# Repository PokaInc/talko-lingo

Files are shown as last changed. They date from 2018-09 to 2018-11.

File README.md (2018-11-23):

# Talko-Lingo
A demonstration project for the re:Invent Builder's Fair 2018

## Abstract

### Talko-Lingo: The multilingual Walkie Talkie

Talko-Lingo enables near real-time communication between two people of the same
or different languages. Users interface with a Walkie Talkie consisting of a
Raspberry Pi embedded into a 3D printed device. After selecting their language,
each user can seamlessly communicate with the recipient, who may be speaking a
different language. The project leverages AWS cloud technologies to encode each
user's voice, transcribe it, translate it to the target language and then
finally convert the translated text to speech. Built-in display mechanisms
provide visual feedback of the translation process.

### Project setup

#### A note for Windows users

The project has been built using Unix-like systems (OSX and Linux), and
therefore our instructions are Unix-oriented. We think that the easiest way to
deploy Talko-Lingo on Windows would be to spin-up a small `Docker` linux
container and follow our instructions, but there is no reason why you couldn't
setup the project on a Windows system using something like `MinGW`. Also, note
that the core of our code is python-based, which is cross-platform so the only
thing an experienced user would have to adapt would be our `bash` and `make`
deploying scripts, which you can work-around with native utilities.

#### Prerequisites: Shared resources

In order to deploy the Cloud resources required by the Talko-Lingo project, we
have prepared some CloudFormation templates for you.

It provisions the following resources:
- An audio bucket that will be used as temporary storage for the audio
processing
- The Tx and Rx lambdas, respectively used for transmitting messages to the
other party and receiving the responses.
- The IoT resources used to publish and subscribe to MQTT topics
- A Web UI to follow the progress of messages through the pipeline

In order to get started, open your AWS console in your browser. On the
command-line you should be able to simply execute the following command to get
things deploying:

```
make deploy-talko-lingo
```

After a couple of minutes, you should start to see resources being created in
your environment:
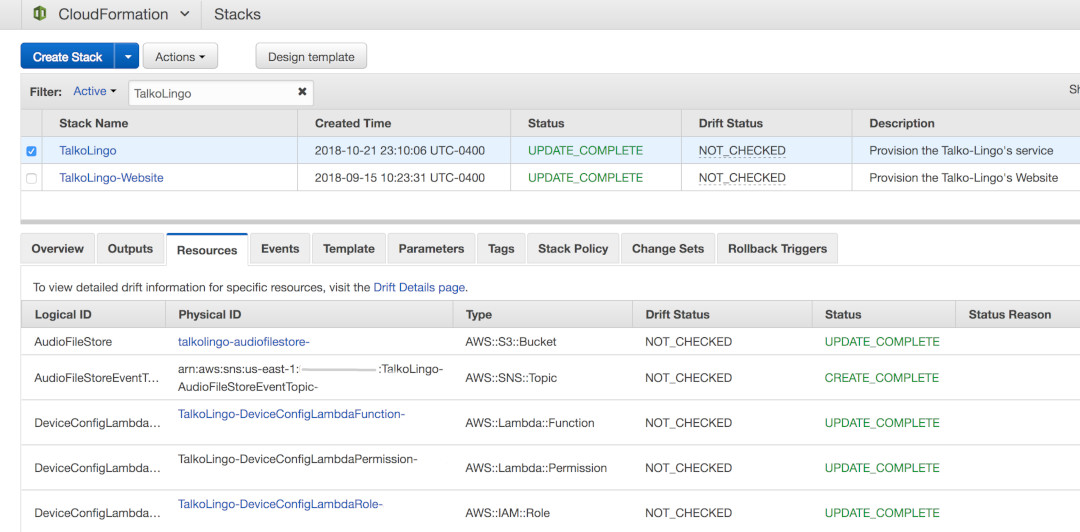
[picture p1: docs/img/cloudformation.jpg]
CloudFormation Cloudformation reosurces


#### Project Setup

In order to complete your own Talko-Lingo pair of Walkie-Talkies, we did put
together a step-by-step tutorial to get you going. Note that these are only
suggestions and we encourage you to make you own version of these if your setup
differs from ours: There are many ways to adapt this project to other types of
hardwares.

2. [Raspberry Pi Software Setup](docs/README_RASPBERRY_PI.md)
3. [Raspberry Pi Hardware Setup](docs/README_HARDWARE.md)
4. [Case 3D Printing](docs/README_3D_PRINTING.md)

If all is went well, you should have a fully-functional Walkie-Talkie setup!
As a bonus, you can tweak it to work over WiFi and communicate over hundreds of
kilometers :-)

And if you want to contribute, of course we accept PRs :-)

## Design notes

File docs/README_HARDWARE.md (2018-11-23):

## Required hardware

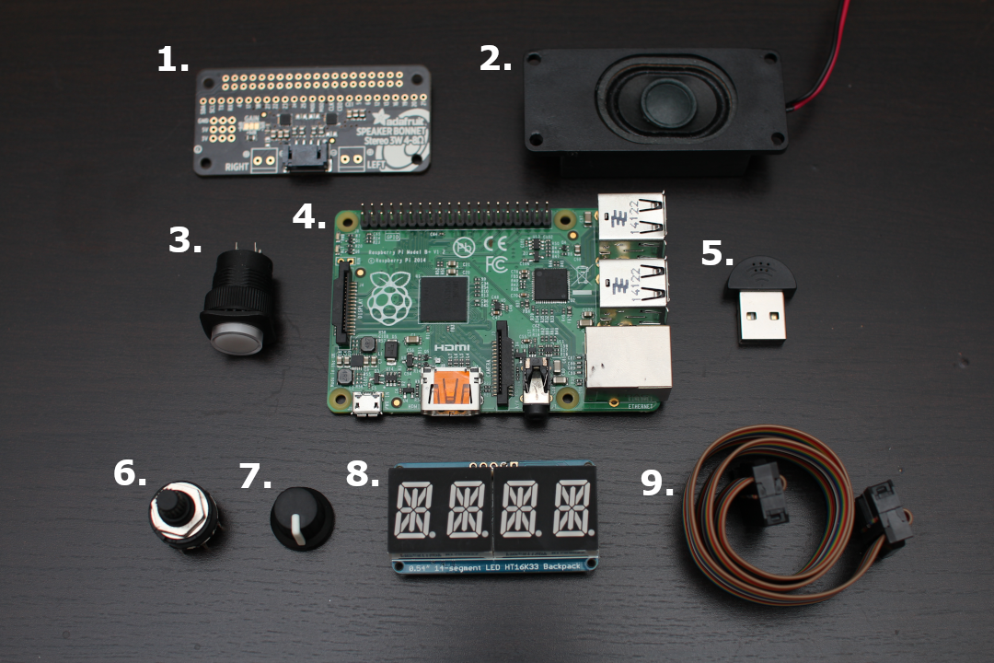
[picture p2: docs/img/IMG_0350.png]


In order to complete this project, you will need two copies of each of those things:

1. **Adafruit's Speaker Bonnet**: An I2S stereo amplifier for the Raspberry Pi. It connects directly to the GPIO and exposes most useful pins. *Warning*: It makes use of pins **19** and **21** even if they are re-exposed. Do not use them if you intend to play sound at the same time. [Available here](https://www.adafruit.com/product/3346)
2. **Adafruit's 3W 4Ohm Speakers**: The speakers normally coming with the bonnet aforementioned. [Available here](https://www.adafruit.com/product/3351)
3. **Adafruit's 16mm Illuminated Pushbutton**: A simple push button equipped with a 3V LED light. [Available here](https://www.adafruit.com/product/1479)
4. **A Raspberry Pi 3**: We made our tests using a Raspberry Pi model B, but a model A, B+ or A+ should work just as well... [Available here](https://www.buyapi.ca/product/raspberry-pi-3-model-b-plus/)
5. **Adafruit's Mini USB Microphone**: A very simple microphone. Be careful, from what we have tested, the quality can be inconsistent... [Available here](https://www.adafruit.com/product/3367)
6. **Adafruit's Mini 8-Way Rotary Selector Switch**: We chose an 8-position rotary switch, but a rotary encoder could be a superior choice. [Available here](https://www.adafruit.com/product/2925)
7. **Adafruit's Potentiometer Knob**: Just to put on the previously mentioned Rotary Selector so that it looks *sexier*. [Available here](https://www.adafruit.com/product/2047)
8. **Adafruit's Alphanumeric Display with its I2C Backpack**: Adafruit has a really easy-to-use LED alphanumeric display, including very well detailed tutorial for Raspberry Pi.. [Available here](https://www.adafruit.com/product/1911)
9. **A flat ribbon cable**: We chose to use a rainbow-colored flat ribbon for ease of use, but really anything you have on-hand will do the job ;-)

## Other required tools

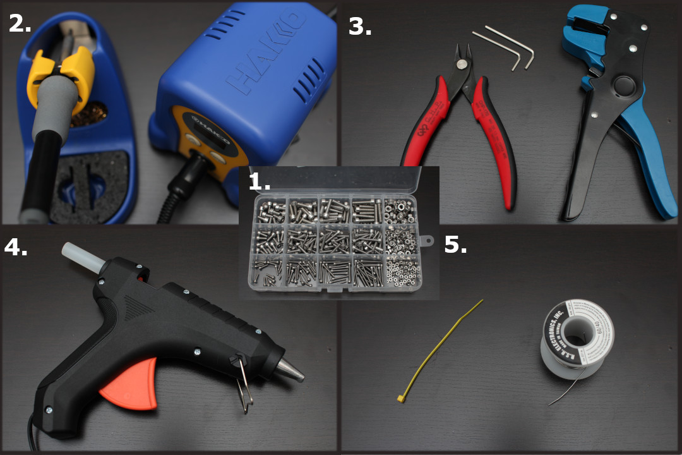
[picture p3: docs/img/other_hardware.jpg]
Required hardware


1. **A set of electronic-sized screws**: Our [3D model]() *--Include Fusion3D gallery link--* includes placeholders for 2mm x 22mm screws. If you don't have the exact screw model we used, you can always modify the model's [parameters](https://www.youtube.com/watch?v=apkUQKNwHIo) to fit your needs.

2. **A soldering iron**: This project requires quite a bit of soldering, so you will have to find a soldering iron. There are a lot of different qualities, but in our case we used the [Hakko FX888D]( https://www.hakko.com/english/products/hakko_fx888d.html) model.

3. **Wire-cutting instruments**: Again, a nice-to-have but those will just make your life easier.

4. **A glue gun with sticks**: This one might not be absolutely necessary, but we found that it helps protecting and solidifying the whole setup against short-circuits and accidental impacts.

5. **Soldering lead**: Of course you will need some lead to do soldering. We used [RSR Electronic's](https://www.elexp.com/ProductDetails.aspx?item_no=060701&CatId=c98e6dbc-415b-4cfe-8661-15f3ec0b88ec) Resin-cored spool. It is much easier to work with for newbies like us, but do not abuse it because it contains toxic chemicals.

## Assembly

### The wires

First, you will need to prepare some cables to connect the components to the speaker bonnet. In our setup, we used these cable lengths:

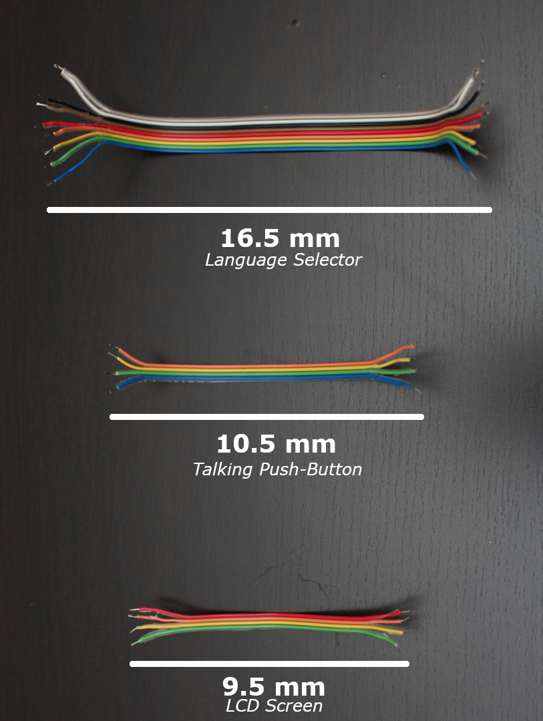
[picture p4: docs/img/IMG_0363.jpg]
Cable lengths


Next, you should begin by soldering the individual components to the aforementioned wires. By convention, we tried to keep red/orange wires for positive DC current and black/blue wires for the ground, but we couldn't follow those standards all the way.

In our case, the result looks like this:

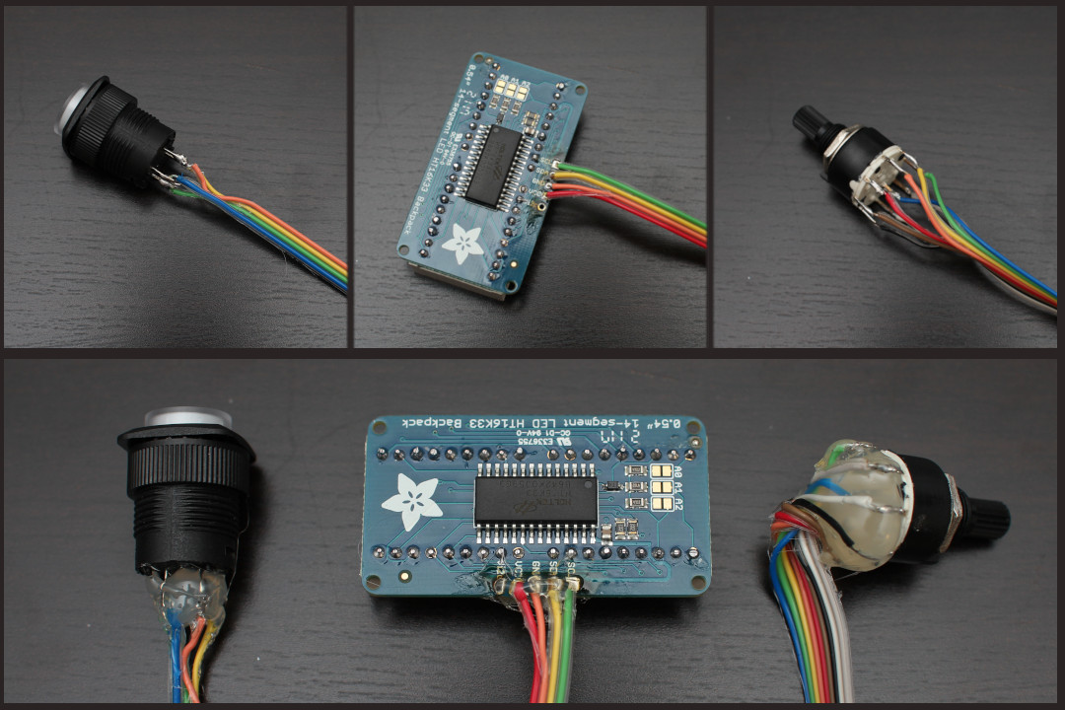
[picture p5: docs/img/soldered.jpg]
Soldered Soldered elements


Notice that as previously said, we used hot glue in order to isolate and harden the fragile wires to our components. There is probably a more professional way, but this one works well for our use-case and is cheap and easy to use.

### The speaking push-button

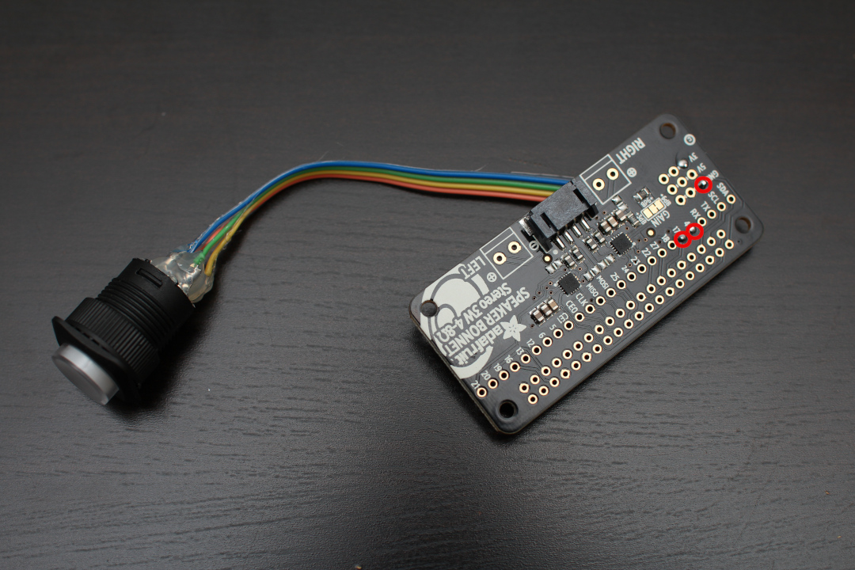
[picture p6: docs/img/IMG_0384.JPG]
PushButton LED Push Button


Once the components are soldered to their wires, you can go-on and begin hooking-them up to the speaker bonnet. We suggest starting with the push-button with the following pin associations:

- The negative (-) pin of the push-button and one of the data pins together in one of the ground pins of the speaker bonnet, since all the ground wires of the circuit are considered the same, and we will need all of them.

- The positive (+) pin of the push-button hooked to the GPIO pin #4 of the speaker bonnet. In theory, we would also need a small resistance (220Ω to 1000Ω) just to be sure, but our tests seem to be conclusives without one...

- The last data pin of the push button to the GPIO pin #17. This will be used to trigger when the user has something to say.

### The LED display

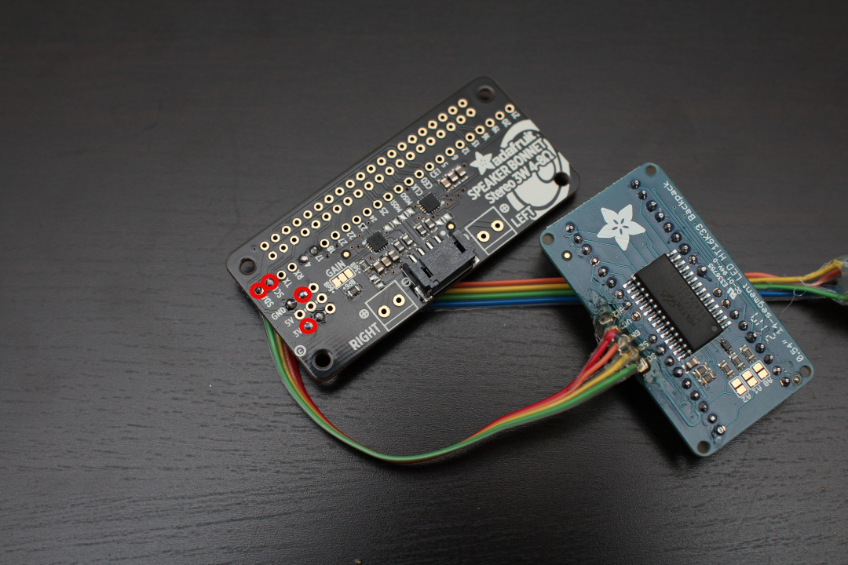
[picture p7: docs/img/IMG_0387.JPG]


This component is pretty straight-forward, you only have 4 wires to solder (plus the LED displays to their backpack, of course...):

- The VCC (+) and GND (-) are soldered to a 3.3V and a ground pin from the speaker bonnet respectively. Note that we do not use the Vi2c pin, so make sure you have the good one.

- SDA and SCL are soldered to their respective pins on the speaker bonnet. **Note that the pins are inverted on the LED backpack compared to the bonnet.** Make sure you don't invert them or it will not work.

### The rotary selector switch

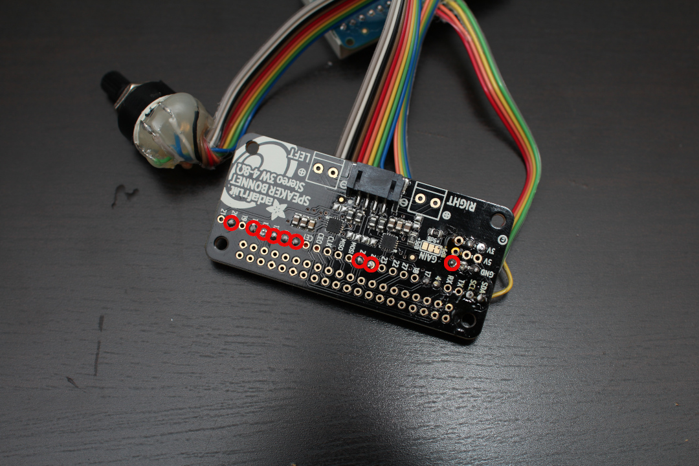
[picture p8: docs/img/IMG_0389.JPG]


This last component needs a little more attention, as there are 9 pins to solder:

- There is a "centered" pin which we will use to connect the ground.

- The other pins will be soldered to GPIO pins #20, 16, 13, 12, 6, 5, 25 and 24.

Note that the choice of pin is arbitraty, but you **cannot choose the pins 19 or 21**, as they are reserved by the speaker bonnet.

### Final result

The final result should look like something similar to this:

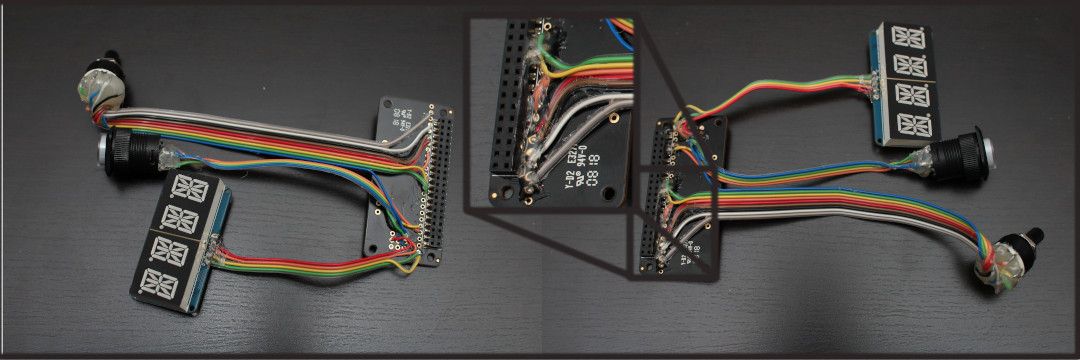
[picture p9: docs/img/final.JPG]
Final result


On the left part, you have the resulting piece of hardware that has just been soldered. But in order to protect our newly soldered wiring, the right side of the picture shows how we used hot glue to isolate and harden a bit our setup.

Proceed to the [next step](README_3D_PRINTING.md) to handle the 3D-printing part of the Talko-Lingo project.

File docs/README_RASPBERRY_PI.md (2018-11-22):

# Raspberry Pi Setup

### Overview
We'll start by configuring the Pi and installing the required softwares. We'll
then clone the project add the appropriate environment variables. Once we get
the code running and we're satisfied wit the setup, we'll duplicate the Micro SD
card so we can get the second Raspberry Pi working without manual interactions.

## Configuring the Pi

### Installing the OS
First you need to get [Raspbian Stretch Lite](https://www.raspberrypi.org/downloads/raspbian/) installed on a Micro SD
Card. I won't go into too much details as there is already great
[documentation](https://www.raspberrypi.org/documentation/installation/installing-images/README.md) that can be found
on the official Raspberry Pi website.

### Getting access to the terminal

There's a few ways to get access to your Raspberry Pi's terminal, but one of the simplest one is just to plug a keyboard
 and a monitor. You'll then need to login, by default the username is `pi` and the password is `raspberry`.

### Basic configuration
In the terminal run the Raspberry Pi configurator:
```
sudo raspi-config
```

#### Change the default password
Considering your Pi will have to be connected to the internet, start by changing the default password to something
else.

#### Network configuration
Open the `Network Options` menu. Change the hostname to something like `talko-a`. Unless you planned to use an ethernet
cable to connect to the internet you'll have to setup the `Wi-fi`. Start by setting the name of your Wi-fi (SSID) and
then input the password. A good way to make sure the Wi-fi was properly configured is to run the `Update` command from
`raspi-config`.

#### Interfacing configuration
Still in `raspi-config`, now navigate to `Interfacing Options`. If you're planning to connect to your Raspberry Pi's
terminal with your computer instead of relying on the keyboard and monitor combo, enable SSH. Then enable I2C as it is
required for the LED display and possibly the speaker bonnet.

### Software installation

In the terminal run the following commands:
```
sudo apt-get update
sudo apt-get install -y build-essential python-dev python-pip python-smbus python-imaging git libportaudio2 portaudio19-dev libsndfile1 libffi-dev mpg321
```

There is a special dependency that needs to be installed for the LED
alphanumerical display to work.
```
git clone https://github.com/adafruit/Adafruit_Python_LED_Backpack.git
cd Adafruit_Python_LED_Backpack
sudo python setup.py install
```

Finally, install [Adafruit's Speaker Bonnet](). You can find the detailed instructions on their [website tutorial](https://learn.adafruit.com/adafruit-speaker-bonnet-for-raspberry-pi/raspberry-pi-usage), but in our case, here is the simplest method what worked for us:

```
curl -sS https://raw.githubusercontent.com/adafruit/Raspberry-Pi-Installer-Scripts/master/i2samp.sh | bash
```

It will ask you to confirm install-steps two times by pressing `y`, then you
will have to reboot the Pi for the changes to take effect.

#### Optional peaker bonnet tweaks

Then, for a clearer sound and to enable volume control, you should follow [these Adafruit instructions](https://learn.adafruit.com/adafruit-speaker-bonnet-for-raspberry-pi/i2s-tweaks) on the Pi:

First, add `dtoverlay=i2s-mmap` to the file `/boot/config.txt`:
```
...
# Enable audio (loads snd_bcm2835)
#dtparam=audio=on
dtoverlay=hifiberry-dac
dtoverlay=i2s-mmap
```

Then modify `/etc/asound.conf` so that it looks like this:

```
pcm.speakerbonnet {
   type hw card 0
}

pcm.!default {
   type plug
   slave.pcm "dmixer"
}

pcm.dmixer {
   type dmix
   ipc_key 1024
   ipc_perm 0666
   slave {
     pcm "speakerbonnet"
     period_time 0
     period_size 1024
     buffer_size 8192
     rate 44100
     channels 2
   }
}

ctl.dmixer {
  type hw card 0
}
```

Which creates a PCM sound device with good default parameters.

Finally, create a new file `/home/pi/.asoundrc`
```
pcm.speakerbonnet {
   type hw card 0
}

pcm.dmixer {
   type dmix
   ipc_key 1024
   ipc_perm 0666
   slave {
     pcm "speakerbonnet"
     period_time 0
     period_size 1024
     buffer_size 8192
     rate 44100
     channels 2
   }
}

ctl.dmixer {
    type hw card 0
}

pcm.softvol {
    type softvol
    slave.pcm "dmixer"
    control.name "PCM"
    control.card 0
}

ctl.softvol {
    type hw card 0
}

pcm.!default {
    type             plug
    slave.pcm       "softvol"
}
```
Reboot in order for your changes to apply. Then, you have to play some sound
using `alsa`:
```
speaker-test -c2 --test=wav -w /usr/share/sounds/alsa/Front_Center.wav
```
And then **reboot again**. Also copy this file to `/root/.asoundrc`:
`sudo cp /home/pi/.asoundrc /root/.asoundrc` and of course **reboot again**.

Then, choose the sound level that you find appropriate for your device using
`sudo alsamixer`. Our testings suggest that 80% is a good level.

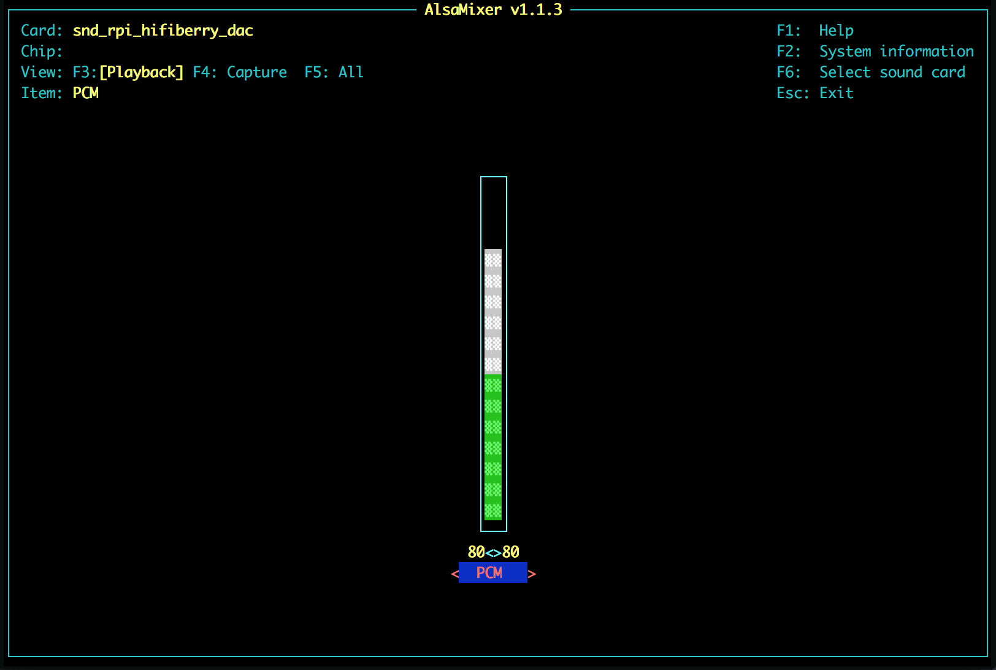
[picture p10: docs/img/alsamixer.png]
Alsa Mixer


*Note*: Never underestimate the power of rebooting when playing with sound on
the Raspberry Pi (and I would say on Linux in general). In our case, it solved
weird problems a couple of times when we were not quite sure what was going on.

### Device-specific AWS resources

For each device of the Talko-Lingo system (typically two), you have to deploy
specific Cloud resources, consisting mostly of what is needed for your device to
authenticate with AWS's `IoT-Data` topics. It will generate certificates which
you can copy to you Raspberry Pi and enable the TalkoLingo service.

To deploy `IoT-Data` credentials to your Raspberry Pi, you can just `make` them:

```
make raspberry-pi-credentials

...make normal outputs...

--------------------------------------------------------
Execute the following on device A terminal:
wget "https://<credentials_bucket>.s3.amazonaws.com/config.zip? \
      AWSAccessKeyId=<ACCESS_KEY_ID>& \
      Signature=<SIGNATURE>& \
      Expires=<TIMESTAMP>" \
      -O config.zip && \
      unzip config.zip -d /home/pi/talko-lingo/.config && \
      rm config.zip
-----------(Link will expire in 15 minutes)-------------
Press enter to continue
```

You can copy-paste this output to your Raspberry Pi; What is happening here is
that when generating the AWS `IoT-Data` credentials, the `make` script uploads
the credentials (certificates) to an S3 bucket and generates a signed link that
only lasts for 15 minutes for security measures. Then, it unzips the files to
the correct configuration directory to be able to publish to the good `IoT-Data`
topic.

### Talko-Lingo installation
In the pi's home directory (`/home/pi`) clone the project:
```
git clone https://github.com/PokaInc/talko-lingo.git
```
cd in the project folder for the next part:
```
cd talko-lingo
```

Install python requirements (be patient it takes a few minutes):
```
cd talko-lingo
pip install -r local_requirements.txt
```

Finally install the `systemd` service on the Raspberry Pi:
```
make install-raspberry-pi-service
```

Which install the `systemd` service associated with the Talko-Lingo software (`rx` and `tx`, which respectively receive and send the audio to the backend).

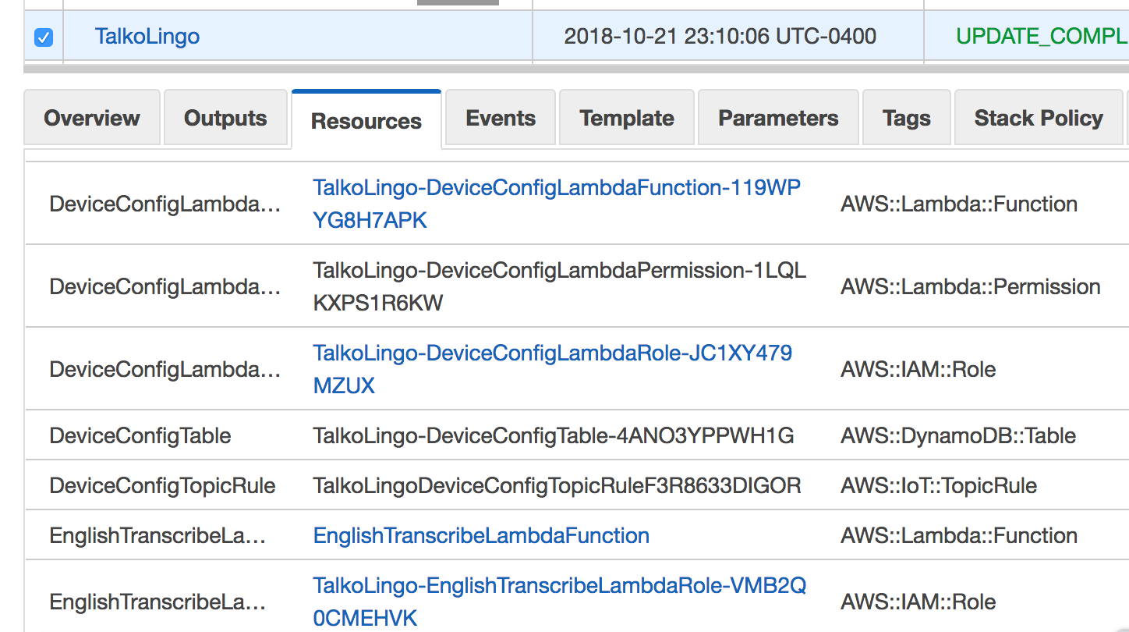
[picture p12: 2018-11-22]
docs/img/cloudformation.png

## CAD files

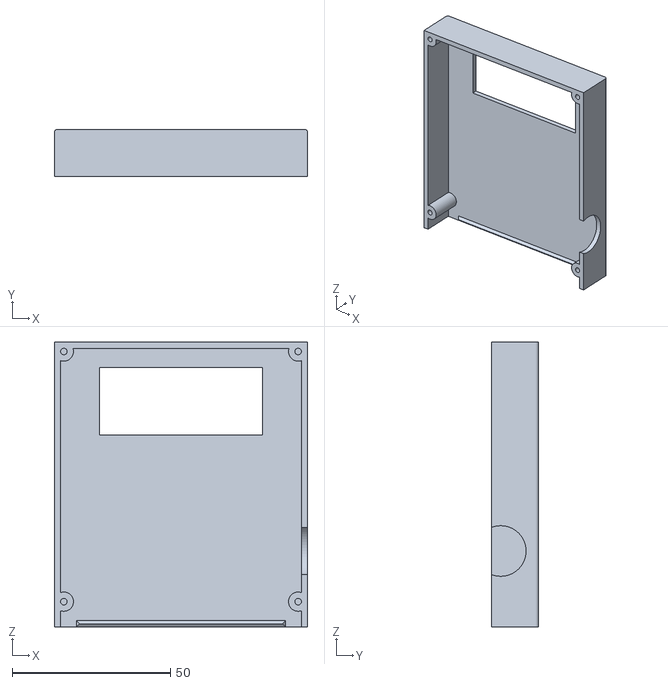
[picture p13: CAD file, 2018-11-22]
3d-printing/top_shell.stl
80.0 x 15.0 x 90.0

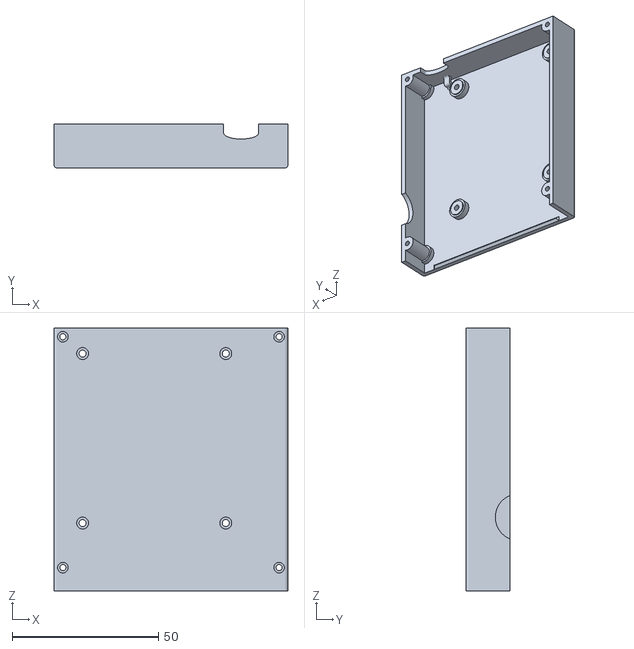
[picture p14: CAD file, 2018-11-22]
3d-printing/bottom_shell.stl
80.0 x 15.0 x 90.0

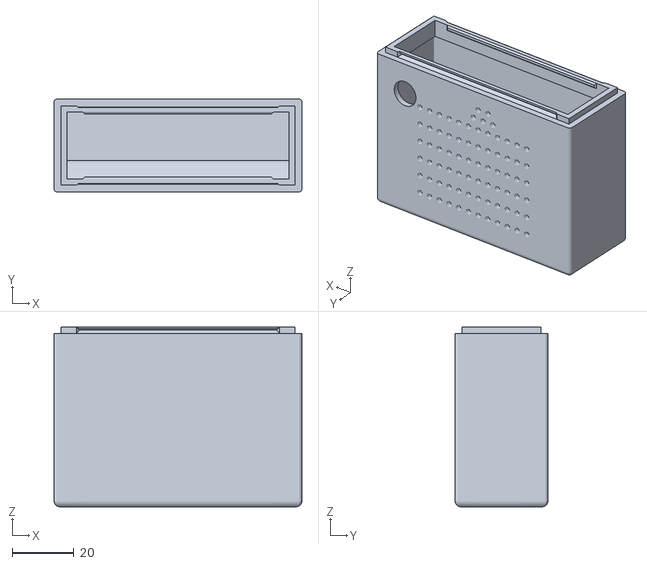
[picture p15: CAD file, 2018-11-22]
3d-printing/speaker_shell.stl
80.0 x 30.0 x 58.0

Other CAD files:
3d-printing/Talko-Lingo.f3d

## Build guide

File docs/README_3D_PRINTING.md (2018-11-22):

## 3D printing & Assembly

### Fusion 360

We designed our case using the [Fusion360](https://www.autodesk.com/products/fusion-360/overview) software. Although it is a commercial product, it is free for hobbyists, you just need to activate your license after installing the free trial.

You will find in the `3d-printing` folder of the present project everything you need to print the plastic-case yourself: the file `Talko-Lingo.f3d` can be imported directly to the Fusion 360 if you wish to make adjustments to the the model (adjusting screw sizes, for example).

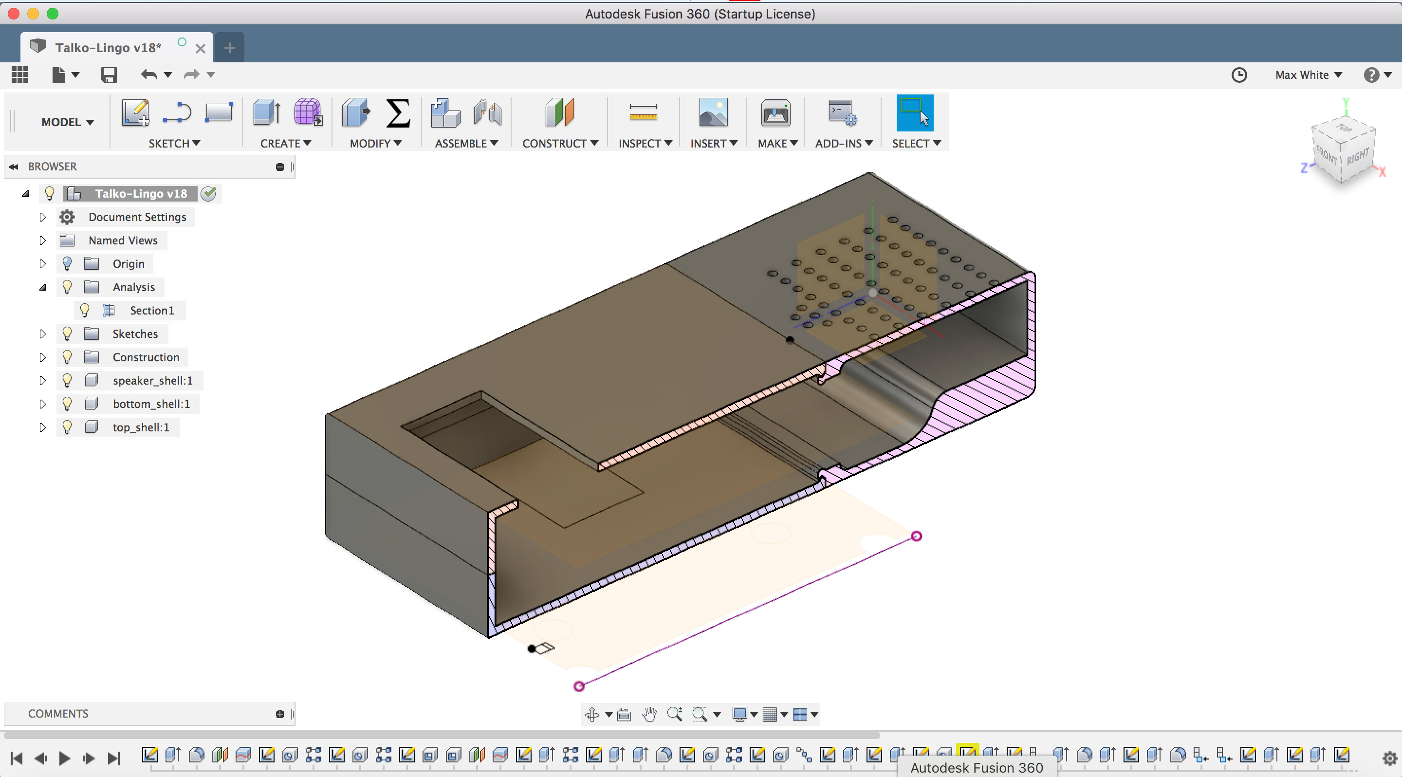
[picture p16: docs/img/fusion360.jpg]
Fusion 360


### Cura

The model is composed of three components: The bottom shell where the Raspberry Pi sits, the top shell where the screen is place and the speaker shell where the speaker, rotary switch and microphone are incorporated. You will find in the `3d-printing` folder of this repository the `STL` file of each of those components which you can send directly to a _slicer_ software like [Cura](https://ultimaker.com/en/products/ultimaker-cura-software).

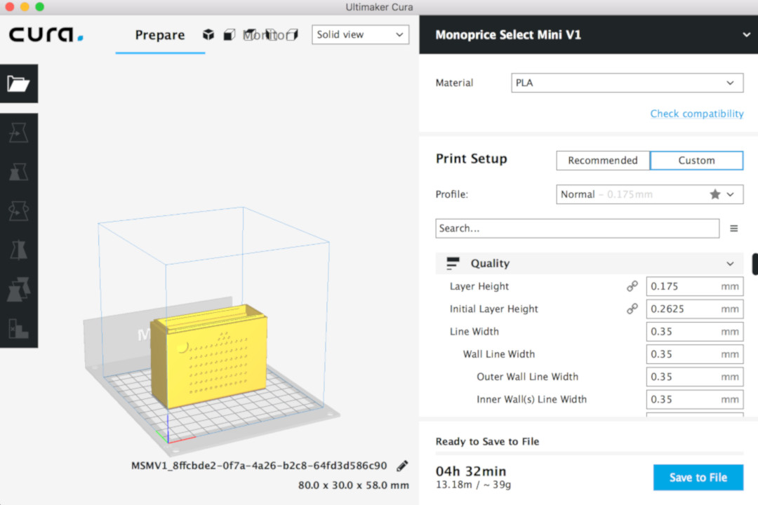
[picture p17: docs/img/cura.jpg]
Cura


It will take care of generating the `gcode` file that most printers will support. There is a pretty large amount of parameters, but Cura has a preset for most popular 3D printers on the market. In our case, we used a [Monoprice MP Select Mini V1](https://www.monoprice.com/product?c_id=107&cp_id=10724&cs_id=1072403&p_id=31429&seq=1&format=2) printer with default settings except for one thing: the `Start G-Code` and `End G-Code`, which we took from [their website](https://mpselectmini.com/starting_ending_g-code_scripts) and gives better overall performance. Our model does not need any "support", we suggest disabling them or you might have a hard time cleaning-up your print afterwards.

#### Starting G-code
 ```
G90 ; set to absolute positioning - this line was added in case Cura doesn't include it by default
M82 ; set extruder to absolute mode - this line was added in case Cura doesn't include it by default (may not be needed)
G28 ; home all axes
; The lines below are to prep the nozzle before a print begins
G1 Z0.2 F1200 ; raise nozzle 0.2mm
G92 E0 ; reset extrusion distance
G1 Y10 ; move Y-Axis (bed) 10mm to prep for purge
G1 X100 E12 F600 ; move X-carriage 100mm while purging 12mm of filament
G92 E0 ; reset extrusion distance
 ```
#### Ending G-code

```
M104 S0 ; turn off hotend/extruder heater
M140 S0 ; turn off bed heater
G91 ; set to relative positioning
G1 E-2 F300 ; retract the filament a bit before lifting the nozzle to release some of the pressure
G1 Z1 ; raise Z 1mm from current position
G1 E-2 F300 ; retract filament even more
G90 ; set to absolute positioning
G1 X20 ; move X axis close to tower but hopefully far enough to keep the fan from rattling
G1 Y120 ; move bed forward for easier part removal
M84 ; disable motors
G4 S360 ; keep fan running for 360 seconds to cool hotend and allow the fan to be turned off - adjust to your needs
M107 ; turn off fan. Don't use M106 S1. Some say M107 doesn't work for them but if the hotend is below 70 degrees it should work
```

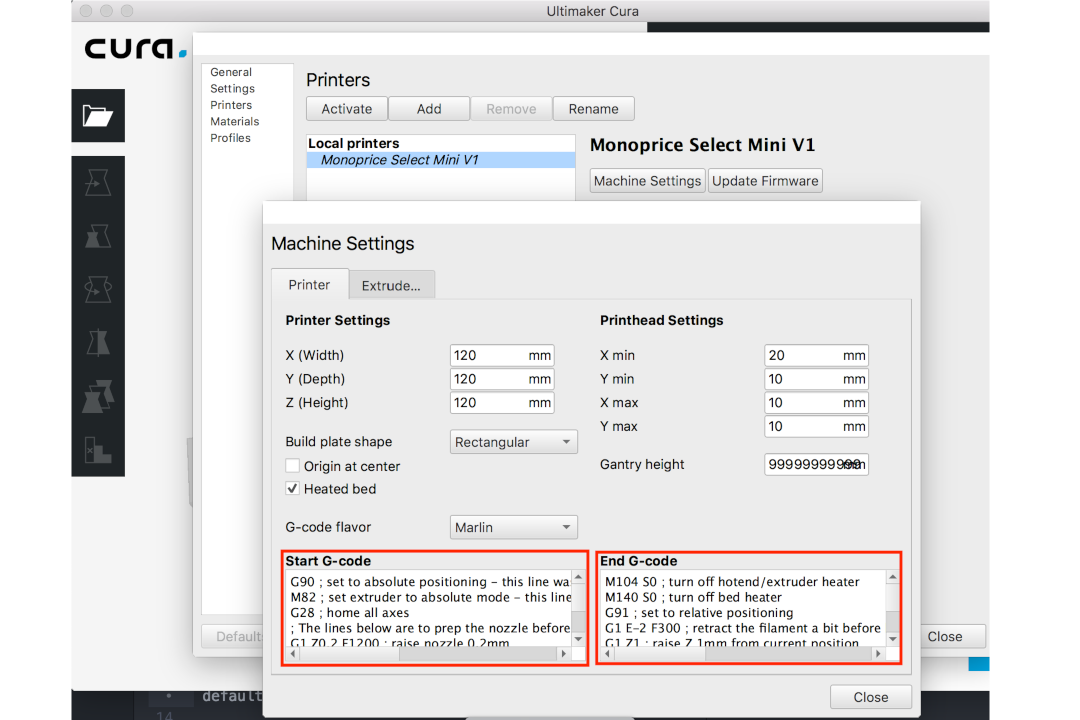
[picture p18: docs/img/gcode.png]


### OctoPrint

Finally, when the model has been sliced and we are satisfied with the preview it gives, the last stage before the actual printer was to upload it to OctoPi, a RaspberryPi equipped with the [OctoPrint](https://octoprint.org) software.

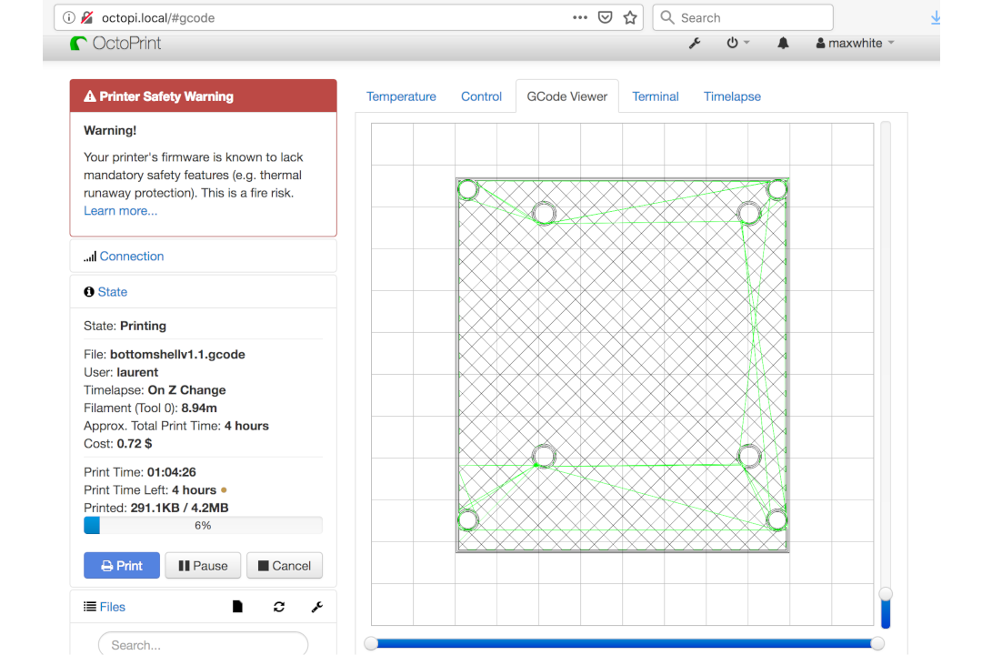
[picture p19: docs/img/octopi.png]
Octoprint


Just verify that all the parameters seem OK, and print-away!

### Results

In the end, you will have those three plastic components:

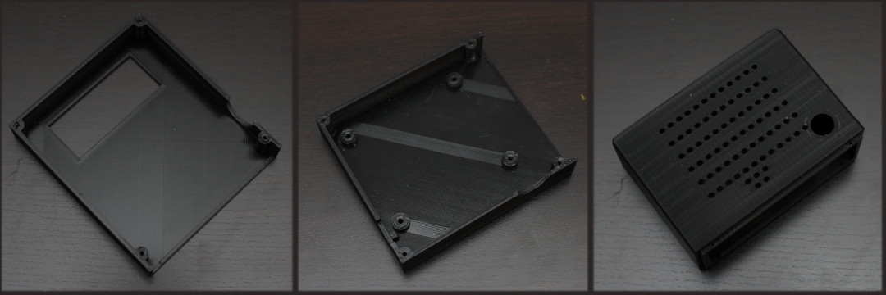
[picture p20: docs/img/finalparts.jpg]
FinalParts Final Parts


Talko-Lingo is now ready to assemble! :-)

Begin by screwing underneath the bottom shell so that screws that align with the Raspberry Pi make it sit properly in place and secure the Pi with small hex nuts. You can also install the microphone in the middle-top USB port just like in this picture:

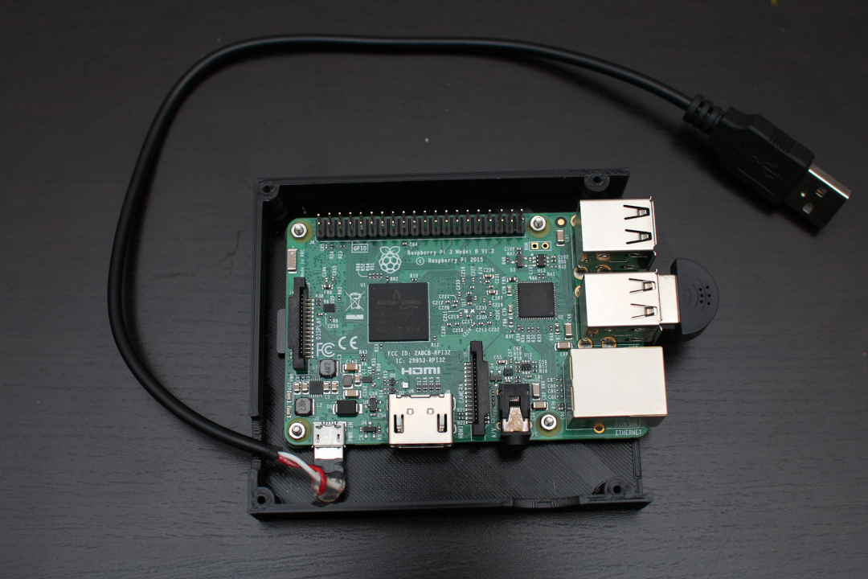
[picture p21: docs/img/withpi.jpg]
WithPi With Pi


Finally, you can put the soldered Speaker Bonnet on the GPIO pins, and cross your fingers that everything works as expected :-) In theory, here the RaspberryPi should have been setup; If it wasn't, go-on a follow the [Raspberry Pi Setup](README_RASPBERRY_PI.md) instructions!

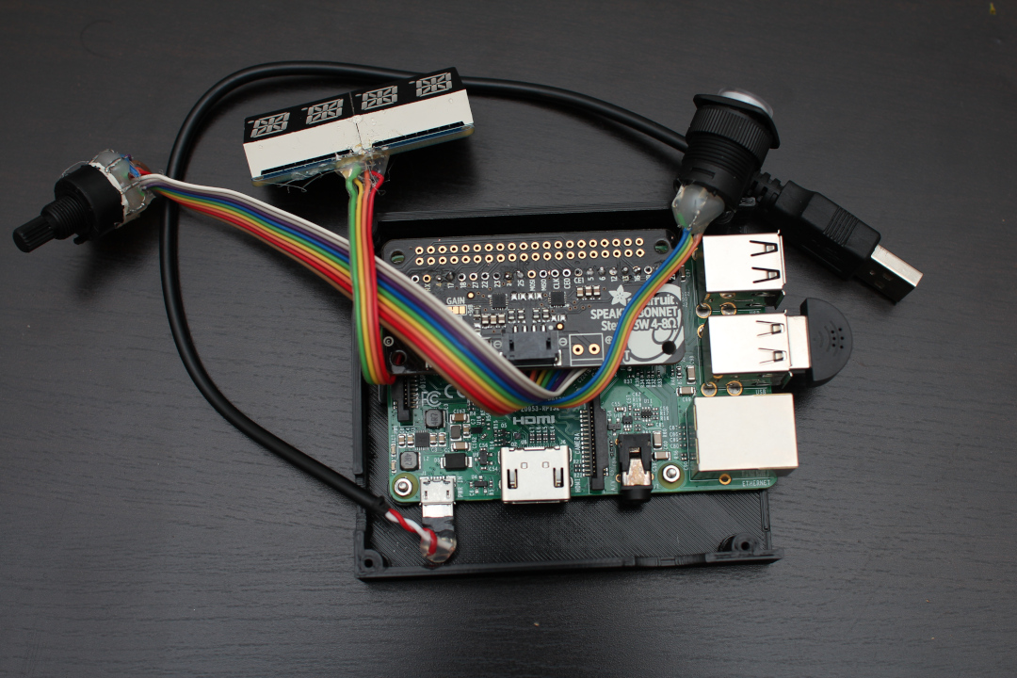
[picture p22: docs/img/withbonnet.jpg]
WithBonnet With Pi


Rinse and repeat to make the second Talko-Lingo device in order to start making new friends from all around the world!

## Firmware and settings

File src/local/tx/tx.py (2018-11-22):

import json
import os
import socket
from time import sleep

import boto3

from audio_recorder import AudioRecorder
from physical_inputs import PhysicalInterface
from shared.display import Display

DEVICE_ID = os.environ['DEVICE_ID']
RECORDING_DEVICE_NAME = os.environ.get('RECORDING_DEVICE_NAME', 'USB PnP Sound Device')
BUCKET_NAME = os.environ['AUDIO_FILE_STORE']
current_language_code = 'en'

iot_client = boto3.client('iot-data')
s3_resource = boto3.resource('s3')
bucket = s3_resource.Bucket(BUCKET_NAME)

display = Display()
print('=== {} READY ==='.format(display.__class__.__name__))


def on_new_recording(recording):
    local_path = recording.filename
    s3_path = 'input/{hostname}/{language_code}/{device_id}/{filename}'.format(
        hostname=socket.gethostname(),
        language_code=current_language_code,
        device_id=DEVICE_ID,
        filename=os.path.basename(recording.filename),
    )
    bucket.upload_file(local_path, s3_path)
    print('File successfully uploaded: ' + s3_path)


def on_language_change(language_code):
    global current_language_code
    current_language_code = language_code
    display.show(language_code)

    iot_client.publish(
        topic='talko/config-topic',
        payload=json.dumps({
            "device_id": DEVICE_ID,
            "lang": language_code,
        })
    )


with PhysicalInterface as physical_interface:
    physical_interface.on_language_change = on_language_change
    print('=== {} READY ==='.format(physical_interface.__class__.__name__))
    with AudioRecorder(RECORDING_DEVICE_NAME) as audio_recorder:
        audio_recorder.completion_callback = on_new_recording
        print('=== {} READY ==='.format(audio_recorder.__class__.__name__))
        try:
            while True:
                physical_interface.tick()
                audio_recorder.tick(physical_interface.is_push_to_talk_button_pressed)
                sleep(0.05)
        except KeyboardInterrupt:
            pass


def dummy_handler(event, context):
    pass

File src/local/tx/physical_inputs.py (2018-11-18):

LANGUAGES = {
    0: 'XXXX',
    5: 'en-AU',
    6: 'en-US',
    12: 'en-GB',
    13: 'es-US',
    16: 'fr-CA',
    20: 'XXXX',
    24: 'XXXX',
    25: 'XXXX',
}

DEV_LANGUAGES = {
    0: 'en-AU',
    1: 'en-US',
    2: 'en-GB',
    3: 'es-US',
    4: 'fr-CA',
}

PUSH_TO_TALK_PIN_NUMBER = 17
PUSH_TO_TALK_LED = 4


class AbstractPhysicalInterface:
    def __init__(self):
        pass

    def __enter__(self):
        return self

    def __exit__(self, exc_type, exc_val, exc_tb):
        pass

    def tick(self):
        pass

    @property
    def is_push_to_talk_button_pressed(self):
        raise NotImplementedError()

    @property
    def language_code(self):
        raise NotImplementedError


class GPIOPhysicalInterface(AbstractPhysicalInterface):
    def __init__(self, gpio, talk_button_pin_number, languages):
        AbstractPhysicalInterface.__init__(self)
        self.gpio = gpio
        self.talk_button_pin_number = talk_button_pin_number
        self.on_language_change = lambda *args: None
        self.selected_pin = 0

    def tick(self):
        selected_pin = next((pin for pin in LANGUAGES.keys() if self.gpio.input(pin) == 0), self.selected_pin)
        if self.selected_pin != selected_pin:
            self.selected_pin = selected_pin
            new_language = LANGUAGES.get(self.selected_pin, LANGUAGES[0])
            self.on_language_change(new_language)

    @property
    def is_push_to_talk_button_pressed(self):
        return not self.gpio.input(self.talk_button_pin_number)

    @property
    def language_code(self):
        return LANGUAGES.get(self.selected_pin, "XX")


class KeyboardPhysicalInterface(AbstractPhysicalInterface):
    def __init__(self, listener, key_module, languages_dev):
        AbstractPhysicalInterface.__init__(self)
        self.languages = languages_dev
        self._shift_key_pressed = False
        self._current_language_code = 0
        self._current_language = DEV_LANGUAGES[0]
        self._listener = listener(on_press=self._on_press, on_release=self._on_release)
        self._key_module = key_module
        self.on_language_change = lambda *args : None

    def __enter__(self):
        self._listener.__enter__()
        return AbstractPhysicalInterface.__enter__(self)

    def __exit__(self, exc_type, exc_val, exc_tb):
        self._listener.__exit__(exc_type, exc_val, exc_tb)

    @property
    def is_push_to_talk_button_pressed(self):
        return self._shift_key_pressed

    @property
    def language_code(self):
        return self._current_language_code

    def _on_press(self, key):
        if key == self._key_module.shift:
            self._shift_key_pressed = True
        elif key == self._key_module.ctrl:
            new_language_code = (self._current_language_code + 1) % 8
            new_language = self.languages.get(new_language_code, "XX")
            self.on_language_change(new_language)
            self._current_language_code = new_language_code
            self._current_language = new_language

    def _on_release(self, key):
        if key == self._key_module.shift:
            self._shift_key_pressed = False


try:
    import RPi.GPIO as GPIO

    GPIO.setmode(GPIO.BCM)
    # Button LED
    GPIO.setup(PUSH_TO_TALK_LED, GPIO.OUT)
    GPIO.output(PUSH_TO_TALK_LED, GPIO.HIGH)
    # Button
    GPIO.setup(PUSH_TO_TALK_PIN_NUMBER, GPIO.IN, pull_up_down=GPIO.PUD_UP)
    # Rotary Switch
    for switch_pin in LANGUAGES.keys():
        GPIO.setup(switch_pin, GPIO.IN, pull_up_down=GPIO.PUD_UP)

    PhysicalInterface = GPIOPhysicalInterface(GPIO, PUSH_TO_TALK_PIN_NUMBER, LANGUAGES)
except ImportError:
    from pynput.keyboard import Key, Listener
    PhysicalInterface = KeyboardPhysicalInterface(Listener, Key, DEV_LANGUAGES)

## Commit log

2018-10-21 Switched to a property
2018-10-21 Working led display and languages switch
2018-10-24 fix GPIO pin
2018-10-24 Wrong bucket name
2018-11-17 Get device config
2018-11-17 Web UI frame
2018-11-18 fix GPIO pins + add button light
    [physical_inputs.py]
2018-11-18 handle 4 letter language codes + device_id in path
2018-11-19 fix assertion for message length in LED display
2018-11-19 fix missing arg to print_str
2018-11-20 increased sample rate to 44100
2018-11-20 add device ids to the job id
2018-11-20 Soldering doc done...
2018-11-21 3D printing README
2018-11-21 Completed 3D printing
2018-11-22 WIP documentation
    [Talko-Lingo.f3d, bottom_shell.stl, speaker_shell.stl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]
2018-11-22 add device id and stricter permission for subscribe
2018-11-22 add device id everywhere + remove csr once used
2018-11-23 Trying to down-sample
